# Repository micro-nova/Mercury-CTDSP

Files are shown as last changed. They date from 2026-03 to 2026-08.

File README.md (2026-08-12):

# Mercury CT-DSP Daughterboard

> An open-hardware analog front-end for continuous-time digital signal processing (CT-DSP) on the MicroNova Mercury 2 FPGA development board.

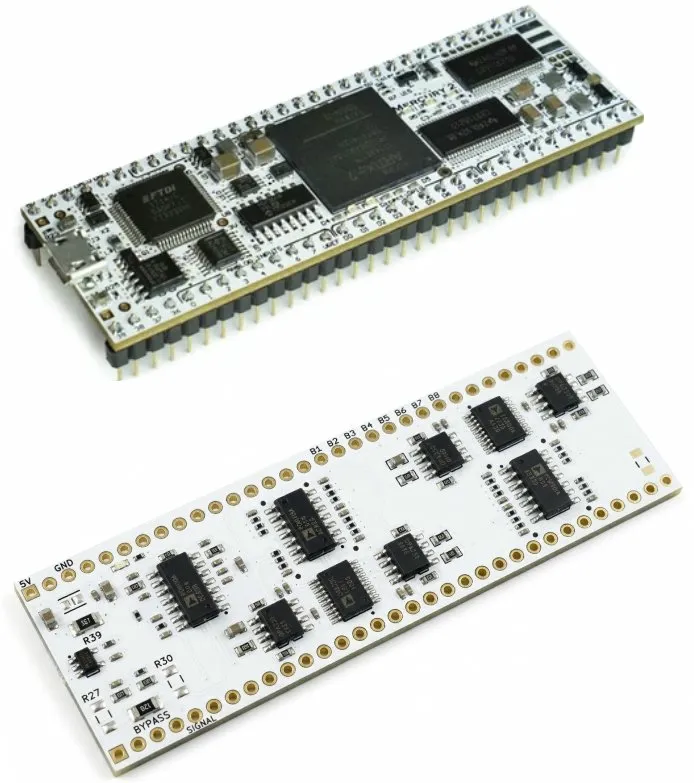
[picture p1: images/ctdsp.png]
Mercury 2 and CT-DSP Daughterboard


This project presents a low-cost, open-source analog daughterboard that converts real-world analog signals into asynchronous level-crossing events suitable for CT-DSP on an FPGA. Unlike conventional sampled-data DSP, CT-DSP processes signals event-driven — reacting only when a signal crosses a threshold — enabling ultra-low latency, reduced data rates, and power consumption that scales with signal activity rather than a fixed sampling clock.

This work was presented at **IEEE SoutheastCon 2026** by Darrin Hanna, Jason Gorski, Joseph Volcic, and Erik Rosenkranz (Oakland University / MicroNova LLC).

---

## Project Overview

Continuous-time digital signal processing (CT-DSP) has historically been confined to simulation or custom ASICs due to the lack of accessible hardware. This project lowers that barrier by providing a complete, reproducible open-hardware platform built around the commercially available MicroNova Mercury 2 FPGA module.

The daughterboard implements an **8-bit, 8-stage level-crossing pipeline architecture**, based on a staged design developed by the DEVCOM Army Research Laboratory. Each stage performs three operations:

1. **Compare** — the input signal is compared against a fixed 2.5 V reference threshold using a fast comparator
2. **Conditional Subtract** — if the input exceeds the threshold, the threshold voltage is subtracted, isolating the residue
3. **Amplify** — the residue is amplified by 2× and passed to the next stage

The comparator output from each stage is routed to the Mercury 2 FPGA, where transitions are detected as level-crossing events. The FPGA firmware timestamps these events and streams them to a host computer over UART/USB.

### System Performance

| Parameter | Value |
|---|---|
| Input Range | 0 – 5 V |
| Resolution | 256 levels (8-bit) |
| Level Spacing | ~19.5 mV |
| Error-free bandwidth | 1.5 kHz (5 V p-p) |
| Worst-case settling time | 352.5 ns (0 V → 5 V step) |
| Single-bit settling time | 114.5 ns (center crossing) |

### Key Components

| Function | Part | Key Specs |
|---|---|---|
| Comparator | TLV3502 | 4.5 ns propagation delay, 16 mV hysteresis |
| Analog Switch | ADG734 | 21 ns t_ON, 2.5 Ω R_ON |
| Stage Amplifier | ADA4891-4 | 170 V/µs slew rate, rail-to-rail output |
| Voltage Reference | REF2025 | 2.5 V precision reference |

### Event Data Format

The link runs a framed, bidirectional protocol (**v2**, firmware ID `0x00000003`) at 3 Mbaud with RTS/CTS flow control. Every frame is COBS-encoded and terminated by a single `0x00` byte, so a `0x00` can never occur inside a frame and resynchronising after a dropped byte is simply "scan to the next `0x00`":

```
<COBS(payload)> 0x00        payload = [type:1] [body...] [crc16:2 LE]
```

`crc16` is CRC-16/CCITT-FALSE over the type byte and body. Device-to-host frame types are `EVENT_BATCH` (`0x01`), `STATUS` (`0x02`), `HELLO` (`0x03`) and `ACK` (`0x04`); the host can send `PING`, `START`, `STOP`, `RESET`, `GET_STATUS`, `SET_SETTLING` and `SET_BATCH`.

Events ship in batches rather than one packet each:

```
EVENT_BATCH  [seq:1][abs_ts:6][n:1][ev_0 .. ev_(n-1)]      ev = [varint dt][bits:1]
```

`abs_ts` is a 48-bit free-running tick count at the device clock rate reported by `HELLO`, and each event's timestamp is the running sum of the deltas. Because every batch carries its own absolute anchor, a lost frame costs exactly that frame — the next one re-anchors itself with no host intervention. `seq` increments per frame and wraps at 256, giving the host a definitive loss detector.

The wire format is specified in full at the top of `Python/ctdsp/protocol.py` and is mirrored bit-for-bit by `frame_tx.vhd` and `cmd_rx.vhd` in the VHDL.

---

## Hardware Setup

### What You Need

- **MicroNova Mercury 2** FPGA development board ([micro-nova.com](https://www.micro-nova.com))
- **CT-DSP Daughterboard** (this project — fabricate from the provided Altium files or order via MicroNova)
- USB-A to Micro-USB cable
- 0–5 V analog signal source (function generator, sensor output, etc.)

### Assembly

1. Align the daughterboard's 64-pin DIP header with the Mercury 2's pin sockets
2. Press firmly to seat — the boards should be flush and parallel
3. Connect the analog input signal to the **SIGIN** pin (see schematic)
4. Apply 5 V and GND to the daughterboard power pins
5. Connect the Mercury 2 to your host computer via USB

### Board Layout

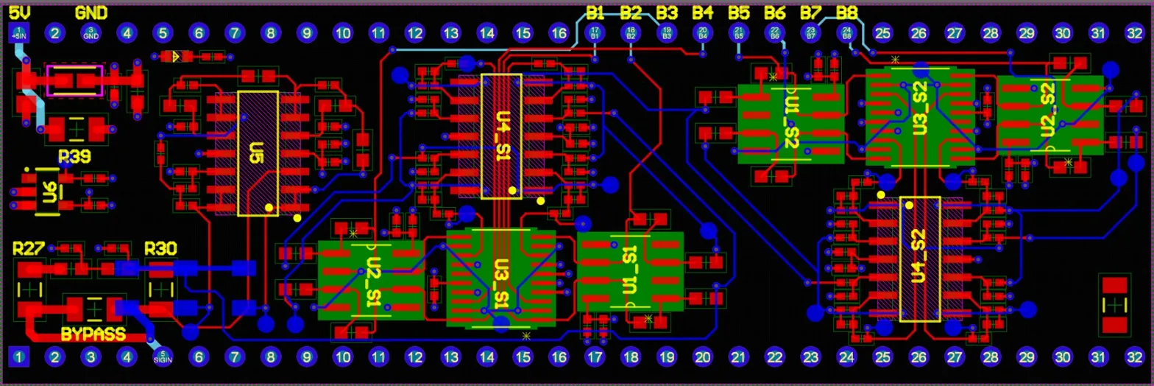
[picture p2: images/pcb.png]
PCB Layout


The PCB follows a modular two-stage-block design. Each block contains one comparator IC, one analog switch, and one amplifier section. Four such blocks are arranged in series across the board for the full 8-stage pipeline. Pin labels B1–B8 along the top edge correspond to the comparator outputs routed to the FPGA.

### Schematic

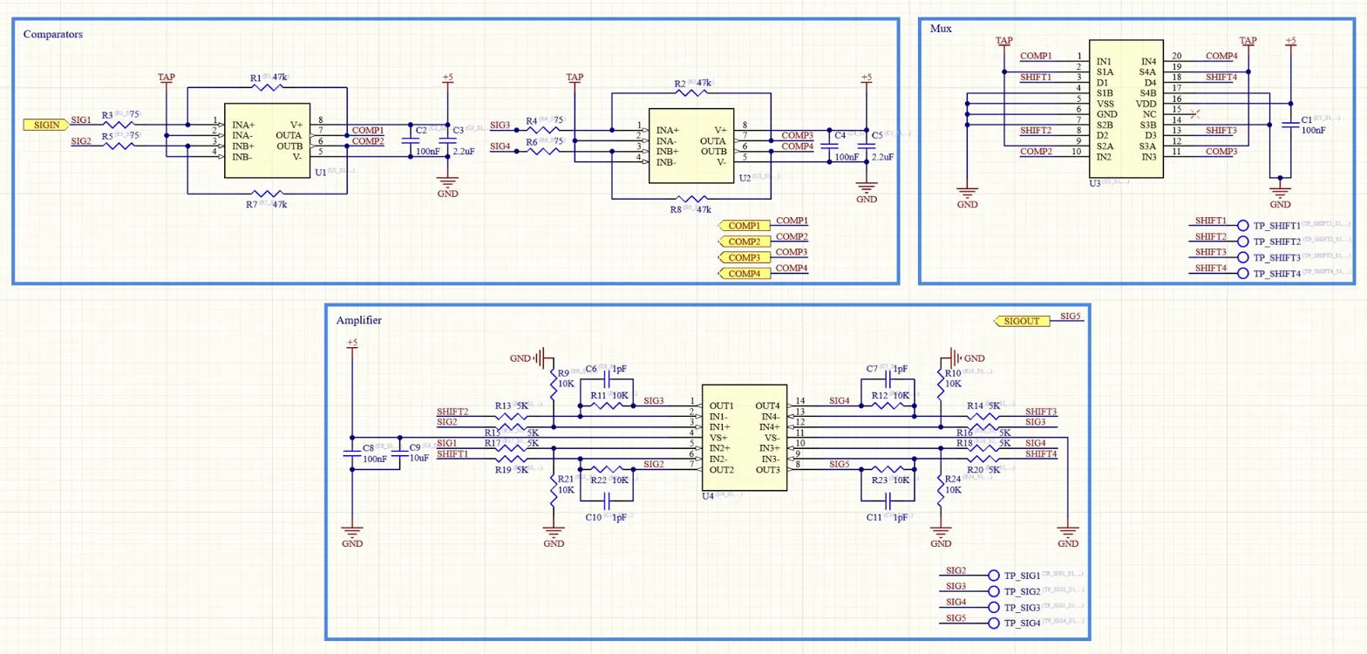
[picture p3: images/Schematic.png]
Schematic


The analog signal path flows from input conditioning through dual comparator stages (U1, U2), into an analog MUX for conditional subtraction (U3), and through instrumentation amplifier stages (U4). The signal path repeats for stages 5–8 on the right half of the board.

---

## Getting Started

### Prerequisites

- **Xilinx Vivado** (2019.1 or later recommended) for VHDL synthesis and FPGA programming
- **Python 3.8+** for host-side data capture and analysis
- Python packages: `pyserial`, `numpy`, `pyqtgraph`, `PyQt5`

```bash
pip install -r Python/requirements.txt
```

Only the live plot needs `pyqtgraph`/`PyQt5`. The codec, the device session and the CLI import cleanly without a GUI stack, so headless capture over SSH or in CI works with just `pyserial` and `numpy`.

### Programming the FPGA

1. Open Vivado and create a new project targeting the **Artix-7 XC7A35T** (Mercury 2)
2. Add the VHDL sources and the `mercury.xdc` constraints file from the Vivado project in `HDL/CT-DSP.zip`
3. Run Synthesis → Implementation → Generate Bitstream
4. Program the Mercury 2 via the USB/JTAG interface

To skip synthesis entirely, program the pre-built **`HDL/dsp_top.bit`** directly. This is the bitstream the Python package expects: protocol v2, firmware ID `0x00000003`.

### Capturing Data with Python

Connect the Mercury 2 via USB. The FTDI part exposes two interfaces and **the CT-DSP is on channel B** — on a bench with more than one FTDI device, pass the port explicitly rather than relying on auto-detection.

```bash
cd Python
pip install -r requirements.txt
```

The fastest check after flashing is a `ping`. A successful `HELLO` confirms the baud rate, framing, CRC and the device's reported clock all at once, before any streaming is involved:

```bash
python -m ctdsp.cli ports              # list serial ports
python -m ctdsp.cli ping COM11         # handshake: protocol, firmware id, clock
python -m ctdsp.cli capture COM11 --count 1000 --csv out.csv
```

For the live plot:

```bash
python receive_ctdsp.py COM11 --window 5 --ticks --time-span 2
```

Three lines is the whole API:

```python
import ctdsp

dev = ctdsp.receive("COM11")                        # opens port, handshakes, streams
ctdsp.plot(dev, window=5, ticks=True, time_span=2)  # live reconstruction
```

`ctdsp.receive()` performs the `HELLO` handshake on open, so a bad baud rate, a stale bitstream or a dead board fails immediately instead of showing up as silence later. `CtdspDevice` is a context manager and `dev.events()` yields decoded events, so headless capture needs no GUI stack:

```python
with ctdsp.receive("COM11") as dev:
    hz = dev.hello.clk_freq_hz          # tick rate comes from the device, not a constant
    for event in dev.events(timeout=5):
        print(event.ticks / hz, event.bits)   # seconds, 8-bit comparator snapshot
```

See `Python/example.py` for the plotting entry point and `python -m ctdsp.selftest` for a self-check of the codec and link.

---

## File Structure

```
Mercury-CTDSP/
├── Altium/                  # Altium Designer hardware files
│   ├── *.SchDoc             # Schematics
│   ├── *.PcbDoc             # PCB layout
│   ├── *.PrjPcb             # Project file
│   ├── ctdsp-v4/            # Revision 4 board
│   └── Project Outputs/     # Gerbers, drill files, pick-and-place, BOM
├── HDL/                     # FPGA firmware for Mercury 2
│   ├── dsp_top.bit          # Pre-built bitstream (proto v2, fw 0x00000003)
│   └── CT-DSP.zip           # Full Vivado 2019.1 project and VHDL sources
├── Python/                  # Host-side capture, decode and plotting
│   ├── ctdsp/
│   │   ├── protocol.py      # Wire-format codec, no I/O
│   │   ├── device.py        # Serial session: handshake, commands, events
│   │   ├── view.py          # Filters and the live plot
│   │   ├── cli.py           # Bring-up tool: ports, ping, status, capture
│   │   └── selftest.py      # Codec and link self-check
│   ├── receive_ctdsp.py     # Live plot, command-line front end
│   ├── example.py           # Minimal three-line usage example
│   └── requirements.txt
├── LTspice3bitstage/        # LTspice simulations of the stage circuit
├── images/                  # Documentation images
│   ├── ctdsp.png
│   ├── Schematic.png
│   └── pcb.png
└── README.md
```

---

## Supported Use Cases

The platform is designed to support multiple entry points depending on background:

- **DSP Practitioners** — Use the pre-loaded bitstream out of the box; connect a signal and stream event data to Python for analysis, with no FPGA or circuit design required
- **FPGA Developers** — Modify the open VHDL source to implement custom CT-DSP processing blocks such as filters, feature detectors, or multi-channel configurations using standard Xilinx tools
- **Embedded Developers** — Deploy CT-DSP algorithms on the Mercury 2's MicroBlaze soft processor in C/C++ for real-time on-board processing
- **Hardware Designers** — Use the provided Altium schematics and PCB layouts as a starting point for custom analog front-end designs, fabricable through any standard PCB service

CT-DSP is particularly well-suited for **sparse signals** such as ECG/biomedical waveforms, speech and audio, and IMU/inertial sensing — applications where signal energy is concentrated in time or frequency, and conventional uniform sampling wastes computation and power.

---

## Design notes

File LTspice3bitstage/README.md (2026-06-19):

See `CTDSP-V7.asc` for current 4 stage implementation.

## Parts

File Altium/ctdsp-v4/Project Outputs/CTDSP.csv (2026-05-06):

Designator | LCSC Part # | Footprint | Name
C1_S1, C1_S2, C2_S1, C2_S2, C4_S1, C4_S2, C8_S1, C8_S2, C12, C15, C17, C18, C20 | C1525 | C_0402 | 100nF
C3_S1, C3_S2, C5_S1, C5_S2 | C12530 | C_0402 | 2.2uF
C6_S1, C6_S2, C7_S1, C7_S2, C10_S1, C10_S2, C11_S1, C11_S2 | C1550 | C_0402 | 1pF
C9_S1, C9_S2, C16 | C15525 | C_0402 | 10uF
C13, C19 | C15195 | C_0402 | 10nF
C14 | C1532 | C_0402 | 22nF
C21 | C1538 | C_0402 | 4.7nF
C22, C23, C26 | C1525 | C_0402 | 0.1uF
C24 | C16780 | C_0805 | 47uF
C25 | C15849 | C_0603 | 1uF
D1 | C2286 | LED_6003 | LED_0603
FB1 | C14709 | BLM18PG121SN1D | BLM18PG121SN1D
J1, J2 |  | DIP32 | DIP32
R1_S1, R1_S2, R2_S1, R2_S2, R7_S1, R7_S2, R8_S1, R8_S2 | C25819 | RES_0603 | 47k
R3_S1, R3_S2, R4_S1, R4_S2, R5_S1, R5_S2, R6_S1, R6_S2 | C4275 | RES_0603 | 75
R9_S1, R9_S2, R10_S1, R10_S2, R11_S1, R11_S2, R12_S1, R12_S2, R21_S1, R21_S2, R22_S1, R22_S2, R23_S1, R23_S2, R24_S1, R24_S2 | C25744 | RES_0402 | 10K
R13_S1, R13_S2, R14_S1, R14_S2, R15_S1, R15_S2, R16_S1, R16_S2, R17_S1, R17_S2, R18_S1, R18_S2, R19_S1, R19_S2, R20_S1, R20_S2 | C5948099 | RES_0402 | 5K
R25, R26, R27, R30, R31, R32, R39, R40 | C17888 | RES_1206 | 0
R28, R35 | C23138 | RES_0603 | 330
R29, R38 | C22978 | RES_0603 | 3.3k
R33 | C25091 | RES_0402 | 220
R34 | C25117 | RES_0402 | 470
R36 | C4190 | RES_0603 | 2.2k
R37 | C22808 | RES_0603 | 150
R41 | C11702 | RES_0402 | 1k
TP_LPSIG1, TP_SHIFT1_S1, TP_SHIFT1_S2, TP_SHIFT2_S1, TP_SHIFT2_S2, TP_SHIFT3_S1, TP_SHIFT3_S2, TP_SHIFT4_S1, TP_SHIFT4_S2, TP_SIG1_S1, TP_SIG1_S2, TP_SIG2_S1, TP_SIG2_S2, TP_SIG3_S1, TP_SIG3_S2, TP_SIG4_S1, TP_SIG4_S2, TP_SIGBUFF1, TP_SIGIN1, TP_TAP_1, TP_TAP_2, TP_TAP_3 |  | TESTPOINT | TESTPOINT
TP_TAP_4 |  | TESTPOINT | TP_TAP_4
U1_S1, U1_S2, U2_S1, U2_S2 | C131165 | TLV3502AIDR | TLV3502AIDR
U3_S1, U3_S2 | C579105 | ADG734BRUZ-REEL | ADG734BRUZ-REEL
U4_S1, U4_S2, U5 | C654290 | ADA4891-4ARZ-R7 | ADA4891-4ARZ-R7
U6 | C962078 | REF2025AIDDCR | REF2025AIDDCR

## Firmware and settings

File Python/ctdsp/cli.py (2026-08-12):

"""Command-line bring-up tool for the CT-DSP board.

    python -m ctdsp.cli ports
    python -m ctdsp.cli ping [PORT]
    python -m ctdsp.cli status [PORT]
    python -m ctdsp.cli reset [PORT]
    python -m ctdsp.cli capture [PORT] --count 1000 [--csv out.csv]
    python -m ctdsp.cli rate [PORT] --seconds 5

`ping` is the single most useful check after flashing: a successful HELLO
confirms the baud rate, framing, CRC and the device's reported clock all at
once, before any streaming is involved.
"""

from __future__ import annotations

import argparse
import csv
import sys
import time
from typing import Optional

from .device import CtdspDevice, DeviceError, find_ports


def _open(port: Optional[str], baud: int, rtscts: bool) -> CtdspDevice:
    if port is None:
        ports = find_ports()
        if not ports:
            raise DeviceError("no serial ports found")
        port = ports[0]
    return CtdspDevice(port, baudrate=baud, rtscts=rtscts)


def cmd_ports(_args) -> int:
    ports = find_ports()
    if not ports:
        print("no serial ports found")
        return 1
    for name in ports:
        print(name)
    return 0


def cmd_ping(args) -> int:
    with _open(args.port, args.baud, not args.no_rtscts) as dev:
        h = dev.hello
        print(f"port          {dev.port}")
        print(f"protocol      v{h.proto_ver}")
        print(f"firmware id   0x{h.fw_id:08X}")
        print(f"device clock  {h.clk_freq_hz:,} Hz  "
              f"({1e9 / h.clk_freq_hz:.4f} ns per tick)")
        print(f"trigger bits  {h.n_bits}")
    return 0


def cmd_status(args) -> int:
    with _open(args.port, args.baud, not args.no_rtscts) as dev:
        s = dev.status()
        print(f"streaming        {s.streaming}")
        print(f"fifo level       {s.fifo_level}")
        print(f"overflow events  {s.overflow_events:,}")
        print(f"frames sent      {s.frames_sent:,}")
        print(f"flags            {s.flags!r}")
        if s.overflowed:
            print("\nThe FIFO has overflowed since the last reset: events were "
                  "dropped on the board itself. Either the event rate exceeds "
                  "what the link can carry, or the host stopped reading.")
    return 0


def cmd_reset(args) -> int:
    with _open(args.port, args.baud, not args.no_rtscts) as dev:
        dev.reset()
        print("device reset: FIFO cleared, counters zeroed, streaming stopped")
    return 0


def cmd_capture(args) -> int:
    with _open(args.port, args.baud, not args.no_rtscts) as dev:
        dev.reset()
        dev.start()
        collected = []
        deadline = time.monotonic() + args.timeout
        try:
            for event in dev.events(timeout=args.timeout):
                collected.append(event)
                if len(collected) >= args.count or time.monotonic() > deadline:
                    break
        except KeyboardInterrupt:
            pass
        dev.stop()

        if not collected:
            print("no events captured -- is anything driving the comparator inputs?",
                  file=sys.stderr)
            return 1

        if args.csv:
            with open(args.csv, "w", newline="", encoding="utf-8") as handle:
                writer = csv.writer(handle)
                writer.writerow(["ticks", "seconds", "bits"])
                base = collected[0].ticks
                for e in collected:
                    writer.writerow([e.ticks,
                                     f"{dev.ticks_to_seconds(e.ticks - base):.9f}",
                                     e.bits])
            print(f"wrote {len(collected):,} events to {args.csv}")
        else:
            base = collected[0].ticks
            for e in collected:
                print(f"{dev.ticks_to_seconds(e.ticks - base):.9f}  "
                      f"{e.ticks:>14}  0x{e.bits:02X}")

        print(f"\n{dev.stats}", file=sys.stderr)
    return 0


def cmd_rate(args) -> int:
    """Measure sustained event throughput -- useful for checking headroom."""
    with _open(args.port, args.baud, not args.no_rtscts) as dev:
        dev.reset()
        dev.start()
        t0 = time.monotonic()
        count = 0
        try:
            while time.monotonic() - t0 < args.seconds:
                count += len(dev.read_events())
                time.sleep(0.01)
        except KeyboardInterrupt:
            pass
        elapsed = time.monotonic() - t0
        dev.stop()
        status = dev.status()

        print(f"{count:,} events in {elapsed:.2f} s = {count / elapsed:,.0f} events/s")
        print(f"device: {status.frames_sent:,} frames sent, "
              f"{status.overflow_events:,} overflow events")
        print(f"host:   {dev.stats}")
        if status.overflow_events:
            print("\nThe board dropped events: the source is faster than the "
                  "link. Raise the baud rate or reduce the event rate.")
    return 0


def main(argv=None) -> int:
    parser = argparse.ArgumentParser(
        description=__doc__, formatter_class=argparse.RawDescriptionHelpFormatter)
    parser.add_argument("--baud", type=int, default=3_000_000)
    parser.add_argument("--no-rtscts", action="store_true",
                        help="disable hardware flow control")
    sub = parser.add_subparsers(dest="command", required=True)

    sub.add_parser("ports", help="list serial ports").set_defaults(func=cmd_ports)

    for name, func, helptext in [
        ("ping", cmd_ping, "identify the device"),
        ("status", cmd_status, "read device counters"),
        ("reset", cmd_reset, "clear FIFO and counters"),
    ]:
        sp = sub.add_parser(name, help=helptext)
        sp.add_argument("port", nargs="?")
        sp.set_defaults(func=func)

    sp = sub.add_parser("capture", help="capture events")
    sp.add_argument("port", nargs="?")
    sp.add_argument("--count", type=int, default=100)
    sp.add_argument("--timeout", type=float, default=10.0)
    sp.add_argument("--csv")
    sp.set_defaults(func=cmd_capture)

    sp = sub.add_parser("rate", help="measure sustained event throughput")
    sp.add_argument("port", nargs="?")
    sp.add_argument("--seconds", type=float, default=5.0)
    sp.set_defaults(func=cmd_rate)

    args = parser.parse_args(argv)
    try:
        return args.func(args)
    except DeviceError as exc:
        print(f"error: {exc}", file=sys.stderr)
        return 1


if __name__ == "__main__":
    sys.exit(main())

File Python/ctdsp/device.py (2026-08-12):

"""Session-oriented interface to a CT-DSP board over the FT2232H channel-B UART.

Typical use::

    with CtdspDevice("COM8") as dev:
        print(dev.hello)              # protocol version, firmware id, clock rate
        dev.start()
        for event in dev.events(timeout=5.0):
            print(event.ticks, event.bits)

The reader runs on a background thread and pushes decoded events into a queue.
Framing recovery is handled entirely by `FrameSplitter`: a corrupt or partial
frame is dropped at the next 0x00 delimiter and the following frame decodes
cleanly, so there is no resynchronisation logic here and no need for the
timestamp-monotonicity and outlier heuristics the v1 reader relied on.
"""

from __future__ import annotations

import queue
import threading
import time
from dataclasses import dataclass
from typing import Iterator, List, Optional

import serial

from . import protocol as p


DEFAULT_BAUD = 3_000_000


class DeviceError(Exception):
    pass


class CommandError(DeviceError):
    """The device rejected a command."""


class TimeoutError_(DeviceError):
    """The device did not reply in time."""


@dataclass
class LinkStats:
    """Everything the host knows about how the link is behaving."""

    events: int = 0
    frames: int = 0
    frames_lost: int = 0     # inferred from gaps in the frame sequence number
    crc_errors: int = 0
    cobs_errors: int = 0
    queue_drops: int = 0     # events discarded because the consumer fell behind

    def __str__(self) -> str:
        return (
            f"events={self.events:,} frames={self.frames:,} "
            f"lost={self.frames_lost:,} crc_err={self.crc_errors:,} "
            f"cobs_err={self.cobs_errors:,} qdrop={self.queue_drops:,}"
        )


class CtdspDevice:
    def __init__(self, port: str, baudrate: int = DEFAULT_BAUD,
                 rtscts: bool = True, queue_size: int = 200_000,
                 auto_hello: bool = True) -> None:
        self.port = port
        self._serial = serial.Serial(
            port,
            baudrate=baudrate,
            timeout=0.05,
            rtscts=rtscts,
        )
        self._splitter = p.FrameSplitter()
        self._events: "queue.Queue[p.Event]" = queue.Queue(maxsize=queue_size)
        self._replies: "queue.Queue[object]" = queue.Queue()
        self._stats = LinkStats()
        self._last_seq: Optional[int] = None
        self._running = True
        self._lock = threading.Lock()

        self.hello: Optional[p.Hello] = None

        self._serial.reset_input_buffer()
        self._reader = threading.Thread(target=self._read_loop, daemon=True,
                                        name="ctdsp-reader")
        self._reader.start()

        if auto_hello:
            self.hello = self.ping()

    # -- context manager ---------------------------------------------------

    def __enter__(self) -> "CtdspDevice":
        return self

    def __exit__(self, *exc) -> None:
        self.close()

    def close(self) -> None:
        if not self._running:
            return
        self._running = False
        try:
            self.stop()
        except DeviceError:
            pass  # closing anyway
        self._reader.join(timeout=1.0)
        self._serial.close()

    # -- reader thread -----------------------------------------------------

    def _read_loop(self) -> None:
        while self._running:
            try:
                pending = self._serial.in_waiting
                data = self._serial.read(pending if pending else 1)
            except (serial.SerialException, OSError):
                if self._running:
                    self._running = False
                return

            if not data:
                continue

            for payload in self._splitter.feed(data):
                try:
                    decoded = p.decode_payload(payload)
                except p.ProtocolError:
                    continue
                self._dispatch(decoded)

            with self._lock:
                self._stats.crc_errors = self._splitter.crc_errors
                self._stats.cobs_errors = self._splitter.cobs_errors

    def _dispatch(self, decoded) -> None:
        if isinstance(decoded, p.EventBatch):
            with self._lock:
                self._stats.frames += 1
                if self._last_seq is not None:
                    gap = (decoded.seq - self._last_seq - 1) & 0xFF
                    if gap:
                        # A sequence gap is unambiguous evidence of loss --
                        # far better than v1's guess-from-the-timestamp.
                        self._stats.frames_lost += gap
                self._last_seq = decoded.seq
                self._stats.events += len(decoded.events)

            for event in decoded.events:
                try:
                    self._events.put_nowait(event)
                except queue.Full:
                    with self._lock:
                        self._stats.queue_drops += 1
        else:
            self._replies.put(decoded)

    # -- commands ----------------------------------------------------------

    def _command(self, frame: bytes, expect, timeout: float = 1.0,
                 retries: int = 2):
        """Send a command and wait for its reply, retrying on timeout."""
        last_error: Optional[Exception] = None
        for _ in range(retries + 1):
            # Drop any stale reply so a late arrival is not mistaken for ours.
            while True:
                try:
                    self._replies.get_nowait()
                except queue.Empty:
                    break

            self._serial.write(frame)
            self._serial.flush()

            deadline = time.monotonic() + timeout
            while True:
                remaining = deadline - time.monotonic()
                if remaining <= 0:
                    last_error = TimeoutError_(
                        f"no reply from {self.port} within {timeout}s")
                    break
                try:
                    reply = self._replies.get(timeout=remaining)
                except queue.Empty:
                    continue

                if isinstance(reply, p.Ack) and reply.status != p.AckStatus.OK:
                    raise CommandError(
                        f"device rejected command 0x{reply.command:02X}: "
                        f"{reply.status.name}")
                if isinstance(reply, expect):
                    return reply
                # Some other frame type; keep waiting within the deadline.

        raise last_error if last_error else TimeoutError_("no reply")
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

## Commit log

2026-03-13 CT-DSP files
    [CTDSP.PrjPcb, CtDPS_Stage.SchDoc, CtDSP_IO.SchDoc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]
2026-05-06 Rev. 0
    Check PCB2.PcbDoc. PCB1 I believe was Rev 3 before the schematic change.
    [CTDSP.PrjPcb, CTDSP.csv, CtDPS_Stage.SchDoc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]
2026-05-06 Rev. 1
    Initial Changes made with Zoe's feedback.
    [CtDPS_Stage.SchDoc, PCB2.PcbDoc]
2026-06-19 Silkscreen Added
2026-08-12 Update host Python package and bitstream to protocol v2
    Replace HDL/dsp_top.bit with the 2026-08-10 build (firmware ID
    0x00000003). The previous bitstream was the 2026-02-26 build, which
    predates protocol v2 and does not respond to PING, so the current host
    code cannot complete the HELLO handshake against it.
    Add the Python host package, which was previously excluded by two
    .gitignore entries and had therefore never been committed:
    ctdsp/protocol.py COBS-framed, CRC16-checked wire codec, no I/O
    ctdsp/device.py serial session: handshake, commands, event stream
    ctdsp/view.py filters and the live plot
    ctdsp/cli.py bring-up tool: ports, ping, status, capture, rate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
    [cli.py, device.py, protocol.py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]
